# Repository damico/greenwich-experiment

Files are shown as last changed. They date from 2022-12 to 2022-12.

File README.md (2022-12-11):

# greenwich-experiment
Radio-Controlled Clock based on GPS receivers

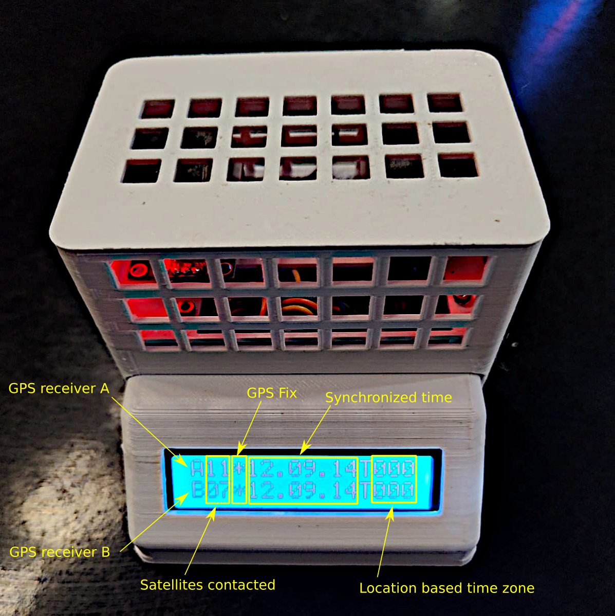
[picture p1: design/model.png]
Working hardware


## Introduction
This is a hardware and software project, and the main idea behind it is to have a clock with time would be collected by 2 different GPS receivers (Which I call receiver A and receiver B). **This is not a GPS disciplined oscillator.**

If you want to know more about  Radio-Controlled Clocks, there is an excelent text written by Michael A. Lombardi from
 National Institute of Standards and Technology (NIST), which can be found here: https://tf.nist.gov/general/pdf/1877.pdf

### Main board
The hardware is based on a BeagleBone Black (BBB) board, which uses [AM3358 Debian 10.3 2020-04-06 4GB SD IoT] (https://debian.beagleboard.org/images/bone-debian-10.3-iot-armhf-2020-04-06-4gb.img.xz) image. 

For Debian image, with SD Cards bigger than 4GB, expand your file system to be able to use all SD Card space `sudo /opt/scripts/tools/grow_partition.sh`. Also to reduce power consumption is important to decrease the cpu frequency. It can be done by editing file **/etc/init.d/cpufrequtils** and changing governor key to `GOVERNOR="powersave"` and then running the following command `systemctl daemon-reload`. Other thing to decrease power consumption is disable HDMI and AUDIO, and this can be done by updating **/boot/uEnv.txt** and adding the following line: `cape_disable=capemgr.disable_partno=BB-BONELT-HDMI,BB-BONELT-HDMIN` and `disable_uboot_overlay_video=1` and `disable_uboot_overlay_audio=1`.

BBB

### GPS receiver A
Ublox M8N

Ublox M8N

### GPS receiver B
Ublox Neo 6 MV2

Ublox Neo 6 MV2

### LCD Display 16X2 (Wich I2C Board)

LCD Display 16X2 (Wich I2C Board)

## GPS receivers communication
The Ublox modules talks with BeagleBone Black (BBB) using UARTs. In this project the UARTs used are: 
 - UART1 (Pins P9_26 RX and	P9_24 TX)	/dev/ttyO1
 - UART4 (Pins P9_11 RX and	P9_13 TX)	/dev/ttyO4 

However these UARTs needs to be accessible. For that, the /boot/uEnv.txt file of BeagleBone Black must be edited with this line `capemgr.enable_partno=BB-UART1,BB-UART4` and with these other 2: `uboot_overlay_addr0=/lib/firmware/BB-UART1-00A0.dtbo`, `uboot_overlay_addr2=/lib/firmware/BB-UART4-00A0.dtbo`

The main software that controls the GPS receiver is the GPSD, which is available on Debian 10. 
The installation of GPSD is done by: `sudo apt-get install gpsd`.
There are 2 main configurations in GPSD:
 - Receivers conf at **/etc/default/gpsd** where devices must be declared as `DEVICES="/dev/ttyO1 /dev/ttyO4"` and options as `GPSD_OPTIONS="-G"`
 - TCP conf at **/lib/systemd/system/gpsd.socket** where ListenStream must be declared as `ListenStream=0.0.0.0:2947`

## Enclosure
The enclusure was projected in FreeCad and 3D printed:



The LCD part was based on this work: https://www.thingiverse.com/thing:614241

## Power Supply
All boards work fine with USB power, but I've also added support for 3.7V 18650 battery, using the battery pins (TP5, TP8) of BBB:



## User Interface
The UI is done through the 16X2 LCD Display, using I2C. 
The software which controls de LCD is written in Python 3 and was based on the work of MilesBDyson, which can be found here: https://github.com/MilesBDyson/I2C-LCD/blob/master/lcd_i2c.py . At **python/** folder there is a lcd_ui.py file which handles the messages into the display. This code requires **psutil** module (`pip3 install psutil`). This code only gets the text data from the files created/updated by the **Time/Location Engine** and displays it on LCD.

In order to make python control the I2C LCD you will need to know the I2C address where the LCD board was connected. For this, first use this command `ls -l /dev/i2c*` to discover if your BBB sees the I2C adapters. It should send a response with at least 1 device. Then, you need to test the adapders with this command `i2cdetect -l`. It should respond with at least this adapter **i2c-0 OMAP I2C adapter**. Finally you need to discover the alocated addresses per adapter, with this command: `i2cdetect -r 0`

## Time/Location Engine
Most of the hard work in terms of software is done by **gpsd** running on Linux, however there are 2 portions of code that I've wrote (both in Java), which grabs the data from gpsd. The first one is the **gpsd.client** (https://github.com/damico/gpsd.client) and the second one is the **greenwich**, that is pushed in this repository (in java/greenwich directory). Both are compiled with maven, but for gpsd.client you should run `mvn clean install -DskipTests`, while for greenwich you should run `mvn clean install -DskipTests package`. Once the .jar package of greenwich was generated, you can run it with this command **java -jar name-of-package.jar**. When the greenwich starts to run it creates 2 files (_dev_ttyO1.gps and _dev_ttyO4.gps) in **/tmp** directory, these files has the GPS Fix data, Satellites data, Time Data and Time zone data. 

## OS integration/automation
In order to have all parts of software working togetter, I've made some bash scripts to install the user interface in python and the time/location engine in java as a init.d service. Take a look at **shell/** directory of this repository to understand how to use it.

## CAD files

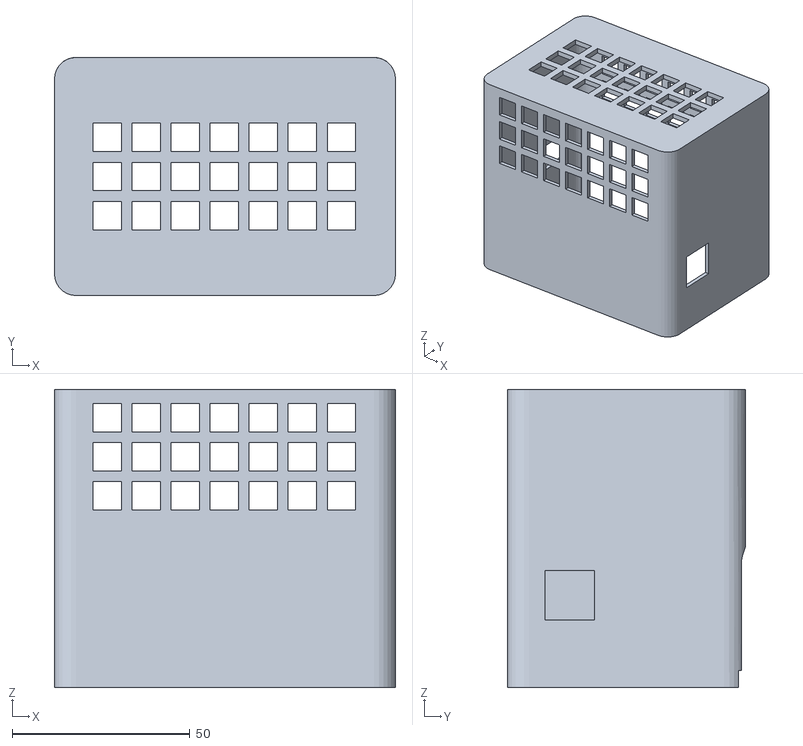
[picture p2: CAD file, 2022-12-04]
3d/outside-frame.stl
96.0 x 67.0 x 84.0

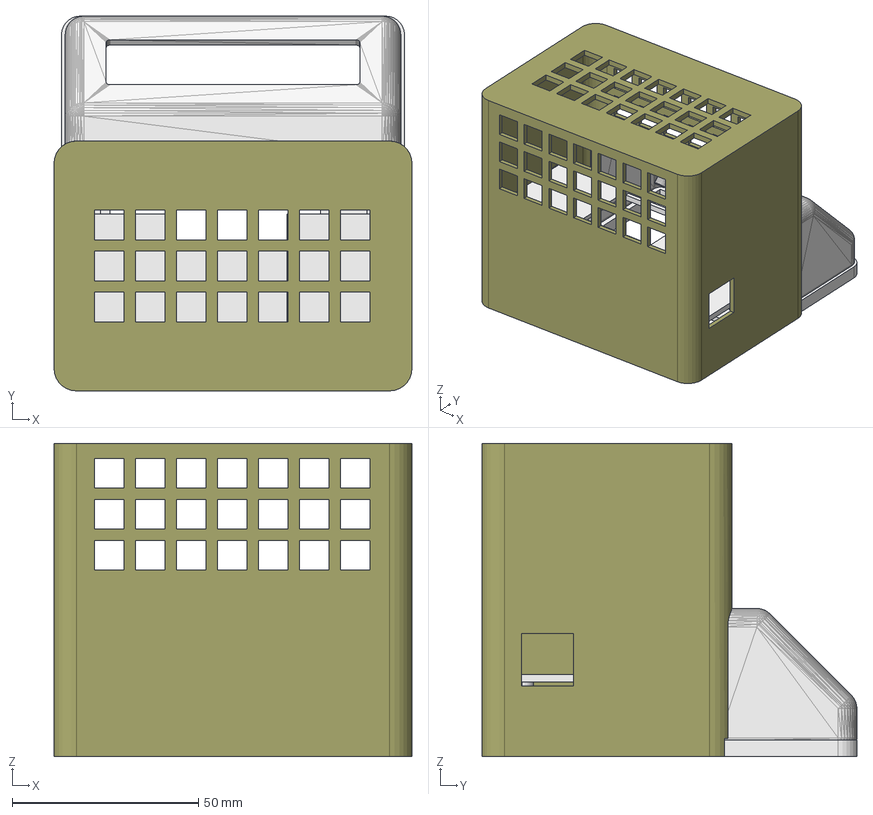
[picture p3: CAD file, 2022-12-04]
3d/BBBCase1.FCStd
96.0 x 100.5 x 84.0 mm
SUP-GPS-B
SUP-GPS-A
MIDDLE-BASE
bottom-base
outside-frame

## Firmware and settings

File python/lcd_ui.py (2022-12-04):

#!/usr/bin/python3

import smbus
import time
import os
import psutil

# device parameters
#I2C_ADDR  = 0x70 # I2C device address
I2C_ADDR  = 0x27
#LCD_WIDTH = 20   # Maximum characters per line
LCD_WIDTH = 16

# device constants
LCD_CHR = 1 # Mode - Will Send Data
LCD_CMD = 0 # Mode - Will Send Commands

LCD_LINE_1 = 0x80 # LCD RAM address for the 1st line
LCD_LINE_2 = 0xC0 # LCD RAM address for the 2nd line
LCD_LINE_3 = 0x94 # LCD RAM address for the 3rd line
LCD_LINE_4 = 0xD4 # LCD RAM address for the 4th line

LCD_BACKLIGHT  = 0x08  # On
#LCD_BACKLIGHT = 0x00  # Off

ENABLE = 0b00000100 # Enable bit

# Timing constants
E_PULSE = 0.0005
E_DELAY = 0.0005

#Open I2C interface
bus = smbus.SMBus(2) # Rev C Beaglebone Black uses 2

def lcd_init():
  # Initialise display
  lcd_byte(0x33,LCD_CMD) # 110011 Initialise
  lcd_byte(0x32,LCD_CMD) # 110010 Initialise
  lcd_byte(0x06,LCD_CMD) # 000110 Cursor move direction
  lcd_byte(0x0C,LCD_CMD) # 001100 Display On,Cursor Off, Blink Off 
  lcd_byte(0x28,LCD_CMD) # 101000 Data length, number of lines, font size
  lcd_byte(0x01,LCD_CMD) # 000001 Clear display
  time.sleep(E_DELAY)

def lcd_byte(bits, mode):
  # Send byte to data pins
  # bits = the data
  # mode = 1 for data
  #        0 for command

  bits_high = mode | (bits & 0xF0) | LCD_BACKLIGHT
  bits_low = mode | ((bits<<4) & 0xF0) | LCD_BACKLIGHT

  # High bits
  bus.write_byte(I2C_ADDR, bits_high)
  lcd_toggle_enable(bits_high)

  # Low bits
  bus.write_byte(I2C_ADDR, bits_low)
  lcd_toggle_enable(bits_low)

def lcd_toggle_enable(bits):
  # Toggle enable
  time.sleep(E_DELAY)
  bus.write_byte(I2C_ADDR, (bits | ENABLE))
  time.sleep(E_PULSE)
  bus.write_byte(I2C_ADDR,(bits & ~ENABLE))
  time.sleep(E_DELAY)

def lcd_string(message,line):
  # Send string to display

  message = message.ljust(LCD_WIDTH," ")

  lcd_byte(line, LCD_CMD)

  for i in range(LCD_WIDTH):
    lcd_byte(ord(message[i]),LCD_CHR)

def checkIfProcessRunning(processName):
  for proc in psutil.process_iter():
    try:
      if processName.lower() in proc.name().lower():
        return True
    except (psutil.NoSuchProcess, psutil.AccessDenied, psutil.ZombieProcess):
        pass
  return False


def get_init_proc(l, c):
  sep = " "
  if c % 2 == 0: sep = "-"
  proc = 'PID BAD'
  if checkIfProcessRunning('java'):
    proc = 'PID OK'
  m = 'INIT ('+proc+') '+str(l)
  m = m.replace(' ', sep)
  return m

def handle_exc(c):
  sep = " "
  if c % 2 == 0: sep = "-"
  m = 'UI ERROR'
  m = m.replace(' ', sep)
  lcd_string(m, LCD_LINE_1)
  print(m)

def proc_msg(f, l, c):
  sep = ":"
  if c % 2 == 0: sep = "."
  m = ''
  if os.path.exists(f):
    with open(f) as file:
      lines = file.readlines()
      m = lines[0]
  else: m = get_init_proc(l,c)
  if l == 1: addr = LCD_LINE_1
  if l == 2: addr = LCD_LINE_2
  m = m.replace(':', sep)
  lcd_string(m, addr)
  print(m, l)


def main():
  counter = 0
  fA = '/tmp/_dev_ttyO4.gps'
  fB = '/tmp/_dev_ttyO1.gps'
  lcd_init()

  while True:
    try:
      proc_msg(fA, 1, counter)
      proc_msg(fB, 2, counter)
    except:
      handle_exc(counter)
    time.sleep(1)
    counter = counter +1


if __name__ == '__main__':

  try:
    main()
  except KeyboardInterrupt:
    pass
  finally:
    lcd_byte(0x01, LCD_CMD)

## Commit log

2022-12-03 changed the references for timezones.csv
    [timezones.csv]
2022-12-03 added first version of lcd_ui.py
    [BBBCase1.FCStd]
2022-12-03 fixed address of i2c
    [lcd_ui.py]
2022-12-03 added data about missing ui file
    [lcd_ui.py]
2022-12-03 fixed return of checkIfProcessRunning
    [lcd_ui.py]
2022-12-03 added doc about how to reduce power comsumption
2022-12-04 added micro usb hole and wifi dongle hole
2022-12-04 fixed wrong preplace call
    [lcd_ui.py]
